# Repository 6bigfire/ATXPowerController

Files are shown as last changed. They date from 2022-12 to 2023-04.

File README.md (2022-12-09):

# ATXPowerController

利用ITX机箱为TinyMonstor小主机（P310S型）扩展了显卡做成了一体机，为了能让显卡的外置ATX电源能够与小主机同步开关机，所以开发了一个基于ArduinoNano的小电源控制器。

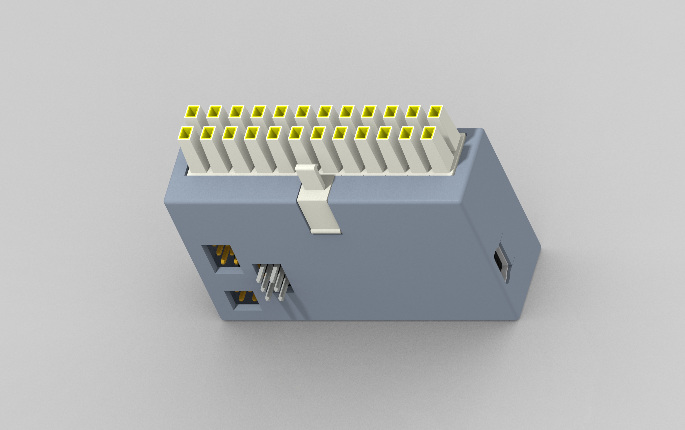
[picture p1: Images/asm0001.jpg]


## 控制器接口说明

看图说话，正常使用时，只需要用到JP2和JP3两个插座。

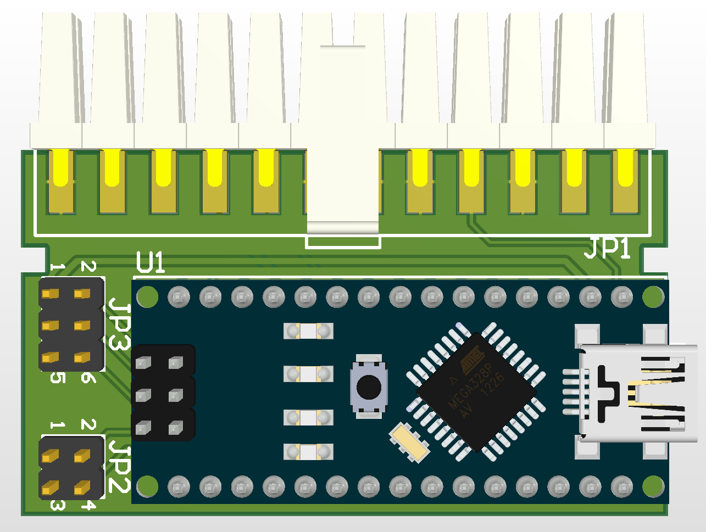
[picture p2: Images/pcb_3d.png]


### JP2 接口说明

JP2连接小主机的开机信号线及主机上电指示。

| 描述  | Pin No. | Pin No. | 描述 |
|:---:|:---:|:---:|:---:|
| | | | |
| GND | 1 | 2 | HOSTCONTROL |
| GND | 3 | 4 | HOSTPOWER |

Pin2 连接小主机的电源控制信号，低电平表示主机电源按钮按下，高电平表示电源按钮放开。

Pin3 连接小主机内的+5V电源，主机上电后为高电平，主机待机时为低电平。

### JP3 接口说明

JP3连接机箱前面板的电源按钮和LED指示灯。

| 描述 | Pin No. | Pin No. | 描述 |
|:-----:|:---:|:---:|:---:|
| | | | |
| +3.3V | 1 | 2 | LED1 |
| GND | 3 | 4 | LED0 |
| GND | 5 | 6 | POWER_BUTTON |

Pin5、Pin6 连接机箱面板的电源按钮，按钮开关本身是无源的，无方向性。

Pin2、Pin4 用来控制机箱前面板LED指示灯，低电平表示灯亮。

## 控制器工作原理

### 输入信号与输出控制之间的逻辑关系

- ATXCONTROL输出状态与HOSTPOWER保持一致，小主机上电时ATXCONTROL输出低电平打开ATX电源，小主机关机时ATXCONTROL输出高电平关闭ATX供电。
- HOSTCONTROL输出状态与POWERBUTTON保持一致，机箱面板电源按钮按下时HOSTCONTROL输出低电平，机箱面板电源按钮释放时HOSTCONTRL输出高电平。
- LED1输出状态与ATXPOWER保持一致，ATX电源打开时LED1输出低电平，ATX电源关断时LED1输出高电平。
- LED0输出状态与HOSTPOWER保持一致，主机开机后LED0输出低电平，主机关机后LED0输出高电平。

| STATUS | STATUS | STATUS | LED | LED | ACTION | ACTION |
| --- | --- | --- | --- | --- | --- | --- |
| | | | | | | |
| HostPower | ATXPower | PowerButton | pinLED0  | pinLED1  | pinHostControl | pinATXControl |
| OPEN | OPEN | — | POWERON  | POWERON  | PowerButton | POWERON |
| OPEN | CLOSE | — | POWERON  | POWEROFF | PowerButton | POWERON |
| CLOSE | OPEN | — | POWEROFF | POWERON  | PowerButton | POWEROFF |
| CLOSE | CLOSE | — | POWEROFF | POWEROFF | PowerButton | POWEROFF |

### 关于显卡外置电源上电跟随主机开关机时，上电顺序的可行性

一般从经验和电气原理上来讲，将外部设备连接到主机的时候都需要先给外部设备接通电源，然后再将信号线与主机连接，这样保证主机与外部设备连接时状态的可靠性。但在目前的设计中选择了将显卡外置电源ATX电源供电与主机供电伴随，那就意味着显卡外置供电上电时间要晚于主机上电时间，虽然在上电顺序上存在着与经验原理不一致的情况，但实际测试效果和使用效果却非常稳定，分析后发现，通过PCIEx16连接的显卡本身已经获得了主板的供电，在小主机上电待机状态下时已经进入了正常的工作状态，显卡的外置供电是属于备用补能供电，上电顺序并不影响主机对显卡的正常检测和配置，这与完全依赖独立供电的热插拔外置设备是有本质的区别的，本次用的控制逻辑精实践检验和理论分析后证明是合理可行的。

## 小主机改造

### 引出HOSTCONTROL

Pin1 连接主板上电源按钮的外壳GND。

Pin2连接在电源按钮旁的贴片三极管的集电极，该脚接地时代表主机电源按钮被按下。



### 引出HOSTPOWER

Pin4 HOSTPOWER 改造如下图所示，连接在了主板声卡芯片的供电电感上，当主机上电时为+5V高电平，主机关机时为低电平。

Pin2 接旁边的GND焊点。



## 一体机成品图





## 把TinyMostor装进ITX机箱中



## 控制器成品图

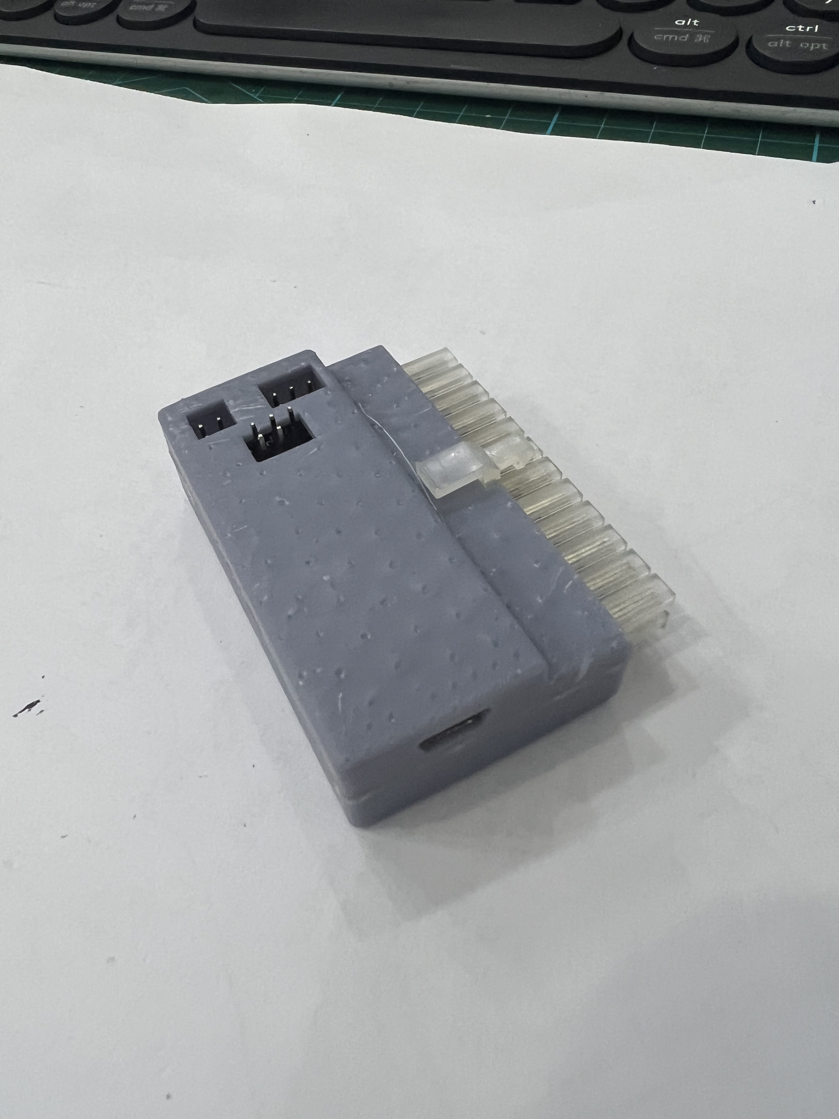
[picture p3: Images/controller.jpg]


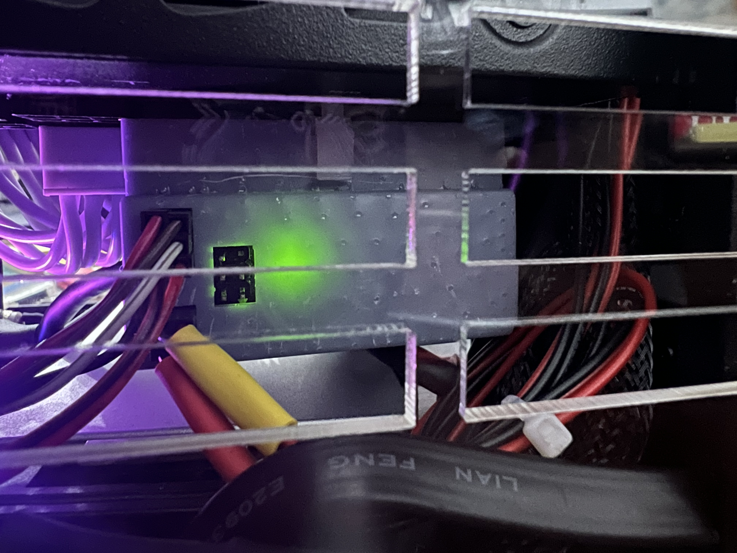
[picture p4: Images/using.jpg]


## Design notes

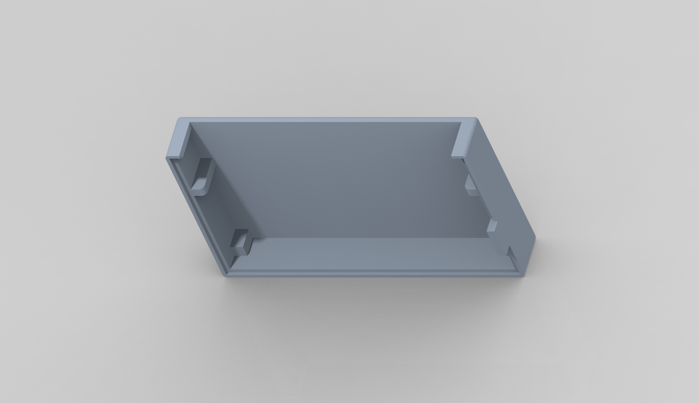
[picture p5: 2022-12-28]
Images/prt0002.jpg

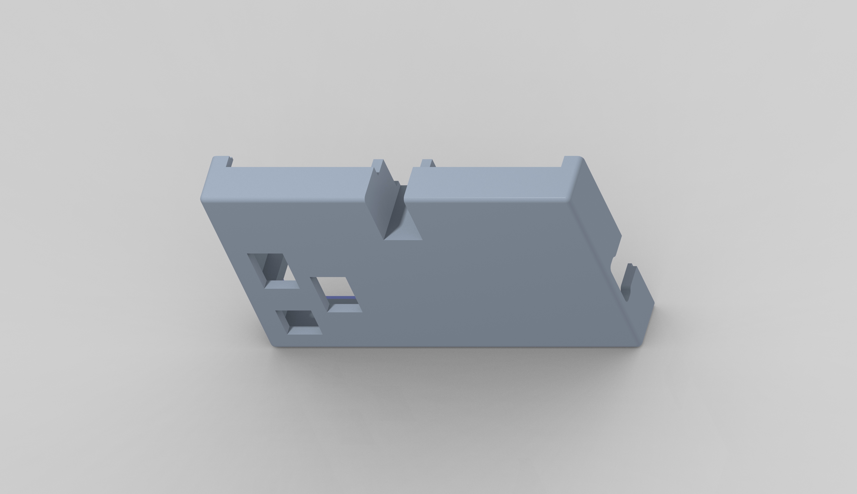
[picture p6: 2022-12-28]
Images/prt0003.jpg

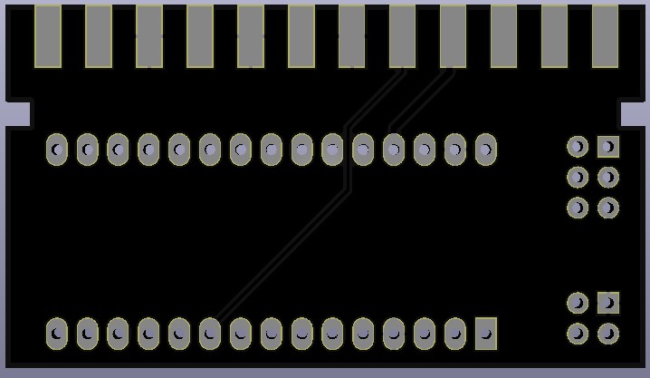
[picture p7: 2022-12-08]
Images/pcb_bot.jpg

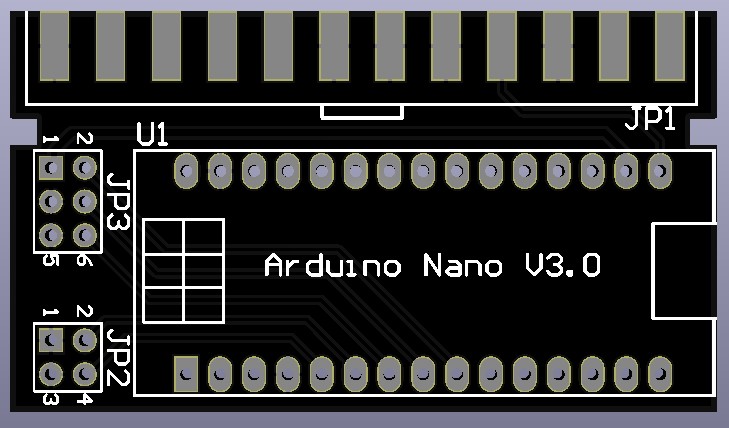
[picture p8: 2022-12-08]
Images/pcb_top.jpg

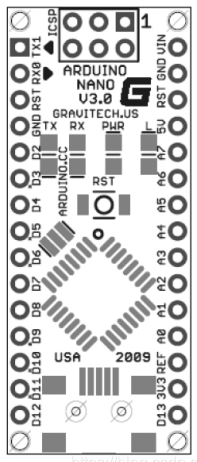
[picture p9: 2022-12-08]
Images/ArduinoNano.png

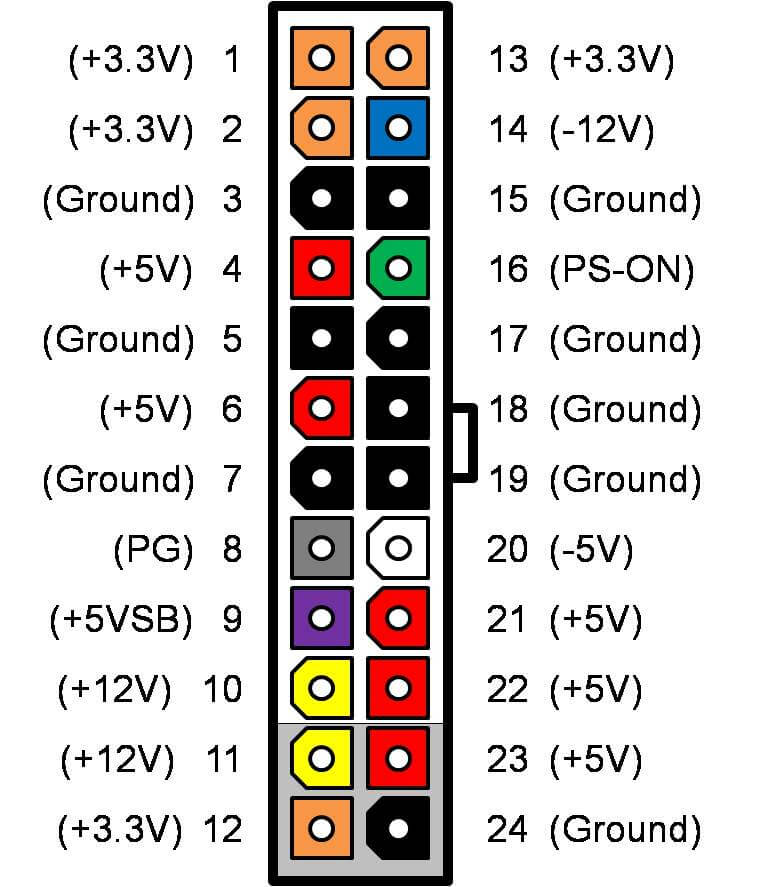
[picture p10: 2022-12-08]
Images/ATX_interface.png

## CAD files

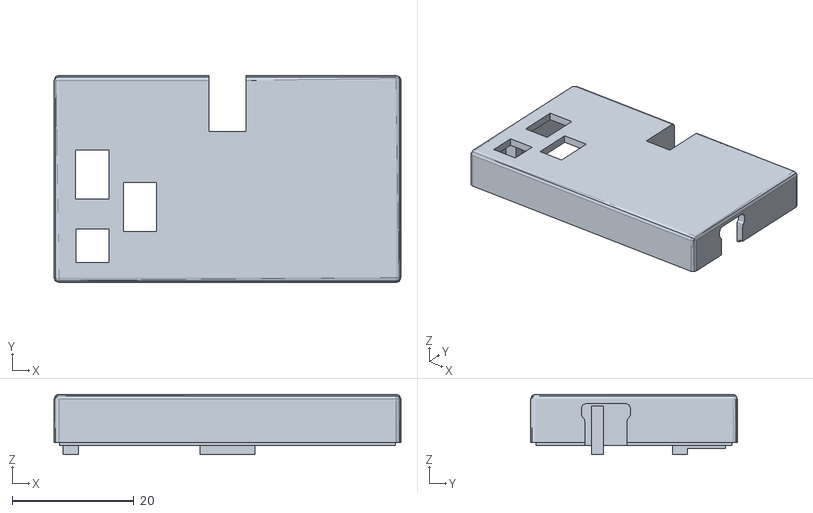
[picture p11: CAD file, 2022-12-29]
shell/prt0003.stl
57.0 x 34.0 x 9.90

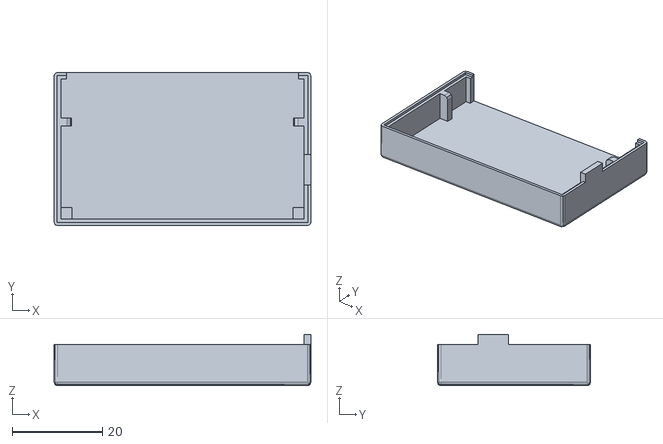
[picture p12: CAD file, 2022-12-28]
shell/prt0002.stl
57.0 x 34.0 x 11.4

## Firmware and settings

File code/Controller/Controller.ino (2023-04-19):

/* State Machine
|             STATUS                 |         LED         |             ACTION             |
|:---------:| -------- | ----------- | -------- | -------- | -------------- | ------------- |
| HostPower | ATXPower | PowerButton | pinLED0  | pinLED1  | pinHostControl | pinATXControl |
| OPEN      | OPEN     | —           | POWERON  | POWERON  | PowerButton    | POWERON       |
| OPEN      | CLOSE    | —           | POWERON  | POWEROFF | PowerButton    | POWERON       |
|           |          |             |          |          |                |               |
|           |          |             |          |          |                |               |
| CLOSE     | OPEN     | —           | POWEROFF | POWERON  | PowerButton    | POWEROFF      |
| CLOSE     | CLOSE    | —           | POWEROFF | POWEROFF | PowerButton    | POWEROFF      |
*/

// constants won't change. They're used here to set pin numbers:
const int pinHostPower      = 2;
const int pinHostControl    = 3;
const int pinPowerButton    = 4;
const int pinLED0           = 5;
const int pinLED1           = 6;
const int pinATXPower       = 7;
const int pinATXControl     = 13;

// variables will change:
#define UP            1
#define DOWN          0
#define OPEN          1
#define CLOSE         0
#define POWERON       0
#define POWEROFF      1

int PowerButton       = UP;  // variable for reading the pinPowerButton status
int ATXPower          = CLOSE;  // variable for reading the pinATXPower status
int HostPower         = CLOSE;  // variable for reading the pinATXControl status

int PowerButtonCount  = 0;
int PBLastStatus      =UP;
int PowerButtonStatus =UP;

void PowerSwitch(int button) {
  if (button <= DOWN ) {
    digitalWrite(pinHostControl, DOWN);
    PowerButtonStatus = DOWN;
  } else {
    digitalWrite(pinHostControl, UP);
    PowerButtonStatus = UP;
  }
}

void setup() {
  // initialize the output pins:
  pinMode(pinHostControl, OUTPUT);
  pinMode(pinATXControl, OUTPUT);
  digitalWrite(pinATXControl, POWEROFF);
  PowerSwitch(UP);

  pinMode(pinLED0, OUTPUT);
  pinMode(pinLED1, OUTPUT);
  digitalWrite(pinLED0, POWEROFF);
  digitalWrite(pinLED1, POWEROFF);


  // initialize the input pins:
  pinMode(pinPowerButton, INPUT_PULLUP);
  pinMode(pinHostPower, INPUT_PULLUP);
  pinMode(pinATXPower, INPUT_PULLUP);
}

void loop() {
  HostPower = digitalRead(pinHostPower);
  ATXPower = digitalRead(pinATXPower);

  if (ATXPower == OPEN) {
    digitalWrite(pinLED1, POWERON);
  } else {
    digitalWrite(pinLED1, POWEROFF);
  } 

  if (HostPower == OPEN) {
    digitalWrite(pinLED0, POWERON);
    digitalWrite(pinATXControl,POWERON);
  } else {
    digitalWrite(pinLED0, POWEROFF);
    digitalWrite(pinATXControl,POWEROFF);
  }
  
  // pinHostControl link to the pinPowerButton:
  PBLastStatus = PowerButton;
  PowerButton = digitalRead(pinPowerButton);

  if (PowerButton == PBLastStatus) {
    PowerButtonCount ++;
    if (PowerButtonCount >= 3) {
      PowerButtonCount = 3;
      if (PowerButton != PowerButtonStatus) PowerSwitch(PowerButton);
    }
  } else {
    PowerButtonCount = 0;
  }
  delay(10);
}

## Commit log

2022-12-08 submit Arduino code
2022-12-08 submit sch&pcb
    [PWR_CTRL.PrjPcb, Sheet1.SchDoc]
2022-12-08 submit socments
    [statemachine.xlsx]
2022-12-08 submit shell
    [prt0002.stl, prt0003.stl]
2022-12-28 改进外壳设计
    改进外壳设计使之便于3d打印
    [prt0002.stl, prt0003.stl]
2023-04-19 code modified
    增加了powerbutton放抖的代码，解决了长按powerbutton主机不能强制关机的问题。
